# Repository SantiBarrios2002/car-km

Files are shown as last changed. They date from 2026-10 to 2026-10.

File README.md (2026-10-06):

# car-km — household car kilometre tracker

Logs every ride of the family car automatically and works out who drove how many kilometres each month.

A small device in the car reads distance from the OBD-II port over Bluetooth and records each ride. Tapping an NFC fob says who is driving. Rides are uploaded over WiFi to a Raspberry Pi at home, and the family uses a phone web app to see monthly totals, assign untapped rides ("that was me") and export CSV.

```
 car                                              home
┌──────────────────────────────────────┐        ┌───────────────────────────────┐
│ Vgate iCar Pro ─BLE─► ESP32-S3 module │  WiFi  │ Raspberry Pi                  │
│ (OBD-II speed)        + carrier PCB   │ ─────► │ FastAPI + SQLite (app/)       │
│ PN532 NFC ─I²C─►      (supercap hold- │  HTTP  │ web app at /, device API      │
│ (who drives)           up, 5 V input) │        │ at /api/  ◄── family phones   │
└──────────────────────────────────────┘        └───────────────────────────────┘
```

## Status

| Part | Where | State |
| --- | --- | --- |
| Pi service + web app | `app/` | **In use** on the family Pi. |
| Carrier PCB | `hardware/carrier/` | Schematic done (ERC clean); first-pass board placed, autorouted and passing DRC. **Not reviewed, not ordered.** |
| Car device firmware | `firmware/` | Not started. Conventions are already fixed in `CLAUDE.md`. |

### Next step: pre-order checks for the carrier PCB

None of these have been done yet. They come before anything is sent to a fab; details and commands are in [`hardware/README.md`](hardware/README.md#next-step-pre-order-checks).

1. **Review the board in KiCad**: placement, power trace widths, the autorouted tracks.
2. **Check the 3D fit** against Waveshare's STEP model (stack height, standoffs, cable paths).
3. **Re-run ERC and DRC** after any changes.
4. **Export the Gerber and drill files** and inspect them in a Gerber viewer.

## Repository layout

```
app/                  Pi service: FastAPI + SQLite, web app and device API
  main.py             all routes (web app + device API), sections marked with # ----
  db.py               schema and SQLite helpers
  static/index.html   the whole web app: one file, vanilla JS, Spanish/English
install.sh            Pi install: venv, systemd unit, nightly backup cron (safe to re-run)
car-km.service        systemd unit template used by install.sh
hardware/             car device hardware: Waveshare module + custom carrier PCB
  README.md           hardware design document: start here for the electronics
  carrier/            KiCad 10 project (schematic + PCB)
  bom-rev2.csv        bill of materials
  vendor/             Waveshare schematic and mechanical drawing (PDF)
CLAUDE.md             working notes for Claude Code and contributors: conventions, hard rules, hardware facts
```

`data/` (database, device token, firmware images, backups) is created at runtime and is not committed.

## Pi service

### Install on the Pi

```bash
git clone <this repo> ~/car-km
cd ~/car-km && chmod +x install.sh && ./install.sh
```

The script creates a venv, installs a systemd unit (`car-km.service`, port 8080) and a nightly SQLite backup cron, then prints the Tailscale URL to share with the family. Logs: `journalctl -u car-km -f`.

### Using it

- Open `http://<pi-tailscale-name>:8080` on a phone (see *Links*). On iOS, Share → *Add to Home Screen* makes it feel like an app.
- The first visit asks *¿Quién eres?*; the answer is remembered on that phone.
- **Ajustes**: add the people. Optionally log the real odometer reading once; after that a ride can be logged by typing the new odometer reading instead of km.
- **Apuntar**: km (or odometer) → Guardar. Rides can be back-dated.
- **Resumen**: monthly totals per person, with unassigned rides highlighted and a *Fui yo* button; the CSV button exports the month.
- Language (es/en) and €/km are set in Ajustes.

### Links (family setup)

| Where | URL |
| --- | --- |
| Anywhere, phone with Tailscale | http://iot-hub.tail8fe499.ts.net:8080 |
| Same, by Tailscale IP (if the name doesn't resolve) | http://100.102.81.29:8080 |
| Home WiFi, no Tailscale needed | http://192.168.1.140:8080 |
| API docs | http://iot-hub.tail8fe499.ts.net:8080/api/docs |

### Giving family members access (Tailscale)

At home the LAN link works for anyone on the WiFi. From outside, each person needs Tailscale. Prefer **sharing the Pi** over inviting people into the tailnet: someone you share with can reach only `iot-hub`, not your other devices.

1. In https://login.tailscale.com/admin/machines, open the **⋯** menu on `iot-hub` → **Share…** and copy the invite link.
2. Send it to the person. They install Tailscale (iOS/Android), sign in with their own Google/Apple/Microsoft account and open the link. They get their own free tailnet with `iot-hub` in it.
3. On their phone: Tailscale on → open the link above → Share / ⋮ → *Add to Home Screen*.
4. To revoke: admin console → **Machines** → `iot-hub` → **Share…** (or the **Sharing** tab) and remove them.

Alternatively, **Users → Invite users** makes them full tailnet members. That's simpler when they have many devices, but by default they can then reach every machine, so restrict them in **Access controls**.

### Device API (used by the car device)

| Method | Path | Auth | Purpose |
| --- | --- | --- | --- |
| POST | `/api/rides/batch` | bearer | JSON array of rides; idempotent on `(device_id, start_ts)` |
| GET | `/api/fobs` | none (also used by the web app) | fob → user map; send `If-None-Match` with the last ETag to get a 304 |
| GET | `/api/time` | bearer | server unix time, for setting the RTC |
| GET | `/api/firmware` | bearer | latest `firmware.bin`; send `X-Version` to get a 304 when current |

Bearer = `Authorization: Bearer <token>`. The token is in `data/device_token`, created on first start and shown in Ajustes. OTA images go in `data/firmware/` (`firmware.bin` + `version.txt`).

Ride object:

```json
{"device_id":"meriva-1","start_ts":1759742400,"end_ts":1759744230,"km":23.4,
 "fob_uid":"04A1B2C3D4E580","source":"obd","fw":"0.3.1","end_reason":"brownout"}
```

Interactive docs at `/api/docs`.

### Development

```bash
python3 -m venv .venv && .venv/bin/pip install -r requirements.txt
.venv/bin/uvicorn app.main:app --reload --port 8081
```

Port 8081 lets the dev server run alongside the live service on 8080. Run from the repo root: the default paths under `data/` are relative to the working directory.

### Security model

There are no logins: the app is reachable only on the home LAN and over Tailscale, and a household km log doesn't need more. The device API uses a bearer token. Don't expose port 8080 to the internet; if wider access is ever needed, put it behind Tailscale Serve or a reverse proxy with authentication.

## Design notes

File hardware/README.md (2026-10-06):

# car-km hardware — Rev 2: Waveshare ESP32-S3-Touch-LCD-2.8 + carrier PCB

The car device is an off-the-shelf **Waveshare ESP32-S3-Touch-LCD-2.8** (ESP32-S3, 2.8" touch display, RTC, Li-ion charger) mounted on a small custom **carrier PCB**. The carrier takes 5 V from the car's USB port, holds the module up for a few seconds after the ignition cuts power (so the ride can be saved), tells the firmware when that happens, and breaks out the PN532 NFC reader and a debug UART. Distance comes from a **Vgate iCar Pro** BLE OBD-II dongle, which needs no wiring.

## Status

| Item | State |
| --- | --- |
| Module facts | Verified against Waveshare's schematic and 2D drawing (`vendor/`), 2026-10-06. |
| Carrier schematic | `carrier/carrier.kicad_sch`, KiCad 10, ERC clean (0 violations). |
| Carrier PCB | `carrier/carrier.kicad_pcb`, first pass: placed, autorouted, DRC clean. **Not reviewed by a person, not ordered.** |
| Parts | Nothing bought yet except the OBD dongle (`bom-rev2.csv`). |

## Next step: pre-order checks

None of these have been done yet. Work through them in order before sending anything to a fab. All commands run from the repo root.

**1. Review the board in KiCad.** Open `hardware/carrier/carrier.kicad_pro`, then the PCB editor. Look at:
- **Routing:** the signals were autorouted (Freerouting) and nobody has looked at them yet. Tidy anything odd, especially the long USB_5V run to the fallback R3/D2. Those two parts aren't fitted by default, so that track could be shortened or moved.
- **Power trace widths:** 0.6 mm, which is the most J3's 1.0 mm-pitch pads and J1's VBUS pins allow. Widen the open runs (J1 → F1 → D1/JP1 → J3, J5 → JP2 → caps) where there is room.
- **Connector positions** against the real stack (see step 2): J1 on the bottom edge, J3 on the left edge, J5 on the right edge, J2 on the top edge.
- **Silkscreen:** pin-1 marks, cap polarity, the JP1/JP2 notes.
- After any edit, refill zones (`B`) before checking.

**2. Check the 3D fit.**
- Install the 3D models (`sudo apt install kicad-packages3d`, or use a KiCad install that has them).
- Download `ESP32-S3-Touch-LCD-2.8_3D.zip` from the [Waveshare wiki](https://www.waveshare.com/wiki/ESP32-S3-Touch-LCD-2.8) into `vendor/`. Don't commit it; it's 20 MB.
- Export the carrier: `kicad-cli pcb export step --subst-models -o hardware/carrier/carrier.step hardware/carrier/carrier.kicad_pcb`.
- Combine the two in FreeCAD (or the KiCad 3D viewer): the module sits on top, parts side facing the carrier, on 8 mm standoffs. Check:
  - **The gap between the boards.** The module's back parts are 6 mm tall, so about 2 mm is left. The carrier's inner face has no parts, but the through-hole leads of J2, J4, C1 and C4 stick out of it: trim them flush or check they clear.
  - **Total depth:** module 10 mm + standoffs 8 mm + carrier 1.6 mm + supercaps 20 mm standing (or ~9 mm lying flat).
  - **Cable paths:**
    - SH-12 cable from J3 round the left edge to module J8, which is in the lower-left quadrant of the module's back, about 12 mm from its left edge;
    - 2-pin cable from J5 to module J1 (BAT);
    - PN532 cable from J2.
  - **USB-C clearance:** a plug in the carrier's J1 near the module's own USB-C, which sits bottom centre.

**3. Re-run ERC and DRC** after any change:

```bash
kicad-cli sch erc --severity-all -o /tmp/erc.rpt hardware/carrier/carrier.kicad_sch
kicad-cli pcb drc --schematic-parity --severity-all -o /tmp/drc.rpt hardware/carrier/carrier.kicad_pcb
```

Expected: ERC 0 violations; DRC 0 errors, 0 unconnected, 0 parity issues. Two warnings are accepted: J1's library silkscreen runs off the board edge where the receptacle overhangs it.

**4. Export the fab files and inspect them.**

```bash
mkdir -p hardware/carrier/fab
kicad-cli pcb export gerbers --check-zones -l F.Cu,B.Cu,F.Paste,B.Paste,F.SilkS,B.SilkS,F.Mask,B.Mask,Edge.Cuts \
  -o hardware/carrier/fab/ hardware/carrier/carrier.kicad_pcb
kicad-cli pcb export drill --excellon-separate-th --generate-map -o hardware/carrier/fab/ hardware/carrier/carrier.kicad_pcb
```

Open the result in `gerbview` (ships with KiCad) or the fab's online viewer before uploading. The board is 2 layers, 1.6 mm, 69.0 × 49.9 mm, with a 0.2 mm minimum clearance and 0.15 mm minimum track (standard JLCPCB/PCBWay rules). `fab/` is not committed.

**After the boards arrive** (before the first car test):
- Change the module's R7 to ≥ 200 kΩ (see *Charge current*).
- Do the bench checks under *Still to verify*.

## The Waveshare module (from its schematic)

| Item | Fact | Consequence |
| --- | --- | --- |
| J8 "12-pin header" | **JST SH 1.0 mm, 12 pins** (`SH1.0-12P`) | The carrier connects with a 12-way SH cable; its J3 is an SH-12 socket. |
| J8 pinout | 1 GND · 2 **USB_5V** · 3 D− (IO19) · 4 D+ (IO20) · 5 GND · 6 3V3 · 7 SCL (IO10) · 8 SDA (IO11) · 9 UART_TXD (IO43) · 10 UART_RXD (IO44) · 11 **GPIO18** · 12 **GPIO15** | 5 V in, I²C, two spare GPIOs and UART on one cable. |
| USB → system | USB_5V → **D3 B5819WS** Schottky → VCC → **ME6217C33** LDO → 3V3 | USB has priority; VCC ≈ USB_5V − 0.3 V. D3 stops the battery rail back-feeding USB_5V. |
| Battery → system | BAT → **Q1 AO3401** (gate: R2 100 k to BAT, pulled low by **T2** when `BAT_Control` = IO7 is high, or by Key1) → **Q2 AO3401** (gate = USB_5V, R29 100 k to GND) → VCC | The battery path is on only when USB is absent **and** the firmware has driven IO7 high. Q2's body diode also conducts once VCC drops ~0.6 V below BAT. |
| Charger | **ETA6098** switching Li-ion charger, input = USB_5V, **RISET R7 = 82 kΩ → 2 A**, CV 4.2 V, 130 mA termination, restarts at −160 mV, input 4.5–5.5 V | Charges whatever is on the battery connector to 4.2 V. |
| Battery connector | J1, labelled **"PH1.25 2P"**: the 1.25 mm MX1.25 / Molex PicoBlade-compatible part (not JST PH 2.0 or GH). Pin 1 = BAT. | The supercap bank plugs in here, via the carrier's J5. |
| Pull-ups | R30 10 k to 3V3 on IO15 (SD_D2), R35 10 k on IO18 (SD_D1) | IO15 already has a pull-up, so the power-loss sense must drive it actively low. |
| BAT_ADC | IO8 reads BAT through 200 k / 100 k | Vbat = 3 × Vadc. |
| Backlight | NPN T3 on **IO5** | Turned off first when power is lost. |
| Antenna | Ceramic chip antenna (CA-C03) + U.FL, **top-left corner** in back view (ESP32 module upper-left, USB-C bottom centre) | Copper keep-out on the carrier under that corner. |
| Mechanical | PCB 69.00 × 49.90 mm, glass 73.06 × 50.54 mm, 10.0 mm total, **6.0 mm of parts on the back**. 4 holes on a **60.00 × 41.00 mm** grid, 4.50 mm in from the edges, Ø ≈ 2.7 mm (M2.5) | The carrier copies the outline and holes; standoffs ≥ 8 mm. |

## Carrier design

Schematic: `carrier/carrier.kicad_sch` (the source of truth for every net).

```
car USB ─ J1 USB-C ─ F1 PTC 1.1 A ─┬─ TVS1 SMAJ5.0A ─ GND
            VIN_CAR      VIN_FUSED ├─ R8 4k7 bleeder ─ GND
                                   ├─ R1 100k ─┬─ R2 11k3 ─ GND
                                   │           └─ U2 TPS3808G01 SENSE      ~RESET → J3.12 (IO15) = PWR_SENSE
                                   │              (VDD = module 3V3 via J3.6, C3 100n)
                                   └─ D1 SS34 ∥ JP1 (bridged) ─┬─ C2 10µF   USB_5V → J3.2
                                                               └─ TP1

module J1 (BAT) ─ cable ─ J5 PicoBlade ─ JP2 (bridged) ─ C1 5F/2.7V ─┬─ C4 5F/2.7V ─ GND
                                                          R4 10k ∥ C1  R5 10k ∥ C4
```

The carrier only protects (F1, TVS1), senses (U2), balances (R4/R5) and connects. Charging and switching to the caps happen on the module.

- **Hold-up.** The module's ETA6098 charges the 2 × 5 F bank (2.5 F, 5.4 V rated) to 4.2 V. When the car cuts power, USB_5V collapses (R8 bleeds it down; the module's D3 stops the board holding it up), Q2 turns on and the board runs from the caps. **Hold-up ≈ 5–7 s** with the backlight off: 2.5 F × (4.2 − 3.6 V) ÷ 0.2 A ≈ 7 s from a full bank, less because the charger only tops up after a 160 mV drop (~4.04 V). Saving the ride takes well under a second.
- **Power-loss sense (U2).** A TPS3808G01 supervisor watches VIN_FUSED through R1/R2 and drives IO15 low with its open-drain `~RESET`; the module's R30 is the pull-up.
  - Trip point: 0.405 V × (1 + 100 k / 11.3 k) = **3.99 V falling**. `~RESET` releases 20 ms after VIN_FUSED recovers (CT open).
  - U2 runs from the module's 3V3, which the caps hold up, so IO15 stays low for the whole hold-up. A supervisor powered from the car side would let IO15 float back high once the car rail fell below ~1 V.
  - A plain resistor divider can't do this job: R30 keeps IO15 high whether the car is on or off.
- **JP1 is bridged by default** (D1 bypassed). D1's drop plus the PTC and cable would leave ~4.4 V at J8, below the ETA6098's 4.5 V minimum input. D1 only matters in the fallback configuration.
- **Charge current.** Everything the module draws, up to 2 A of charge current included, comes in through J8 pin 2: one SH contact rated about 1 A, behind F1 (1.1 A hold). **Change the module's R7 (0402, back side) from 82 k to ≥ 200 k (≈ 0.8 A)** before the first car test. Recharging an empty bank then takes ~15 s instead of ~5 s.
- **Firmware duties:** drive IO7 (`BAT_Control`) high at boot and never low, otherwise the caps are never connected. Leave the microSD slot empty or use 1-bit SD mode, because IO15 is also SD_D2.

### Fallback configuration

This is for the case where the bench test shows the module's charger misbehaving with a capacitor load. Footprints for the Rev 1 circuit are on the board, unpopulated (DNP):
- **R3** (22 Ω, 1 W) from USB_5V to VCAP;
- **D2** (SS34) from VCAP back to USB_5V.

To switch over:
1. Cut JP1, so that D1 blocks back-feed into the car port.
2. Cut JP2.
3. Leave J5 unconnected.
4. Fit R3 and D2.

The caps then charge to ~4.7 V from the 5 V side and discharge into USB_5V through D2. Hold-up ≈ 2.5 F × (4.4 − 3.9 V) ÷ 0.2 A ≈ 6 s.

### Nets (summary)

| Net | Pins |
| --- | --- |
| VIN_CAR | J1 VBUS (A4, A9, B4, B9), F1.1 |
| VIN_FUSED | F1.2, TVS1 K, D1 A, JP1.1, R1.1, R8.1 |
| USB_5V | D1 K, JP1.2, C2.1, J3.2, TP1, R3.1 (DNP), D2 K (DNP) |
| SENSE_DIV | R1.2, R2.1, U2.5 SENSE |
| PWR_SENSE | U2.1 ~RESET, J3.12 |
| BAT | J5.1, JP2.1 |
| VCAP | JP2.2, C1 +, R4.1, TP2, R3.2 (DNP), D2 A (DNP) |
| VCAP_MID | C1 −, C4 +, R4.2, R5.1 |
| +3V3 | J3.6, J2.1, U2.6 VDD, U2.3 ~MR, C3.1 |
| SCL / SDA | J3.7 / J3.8 → J2.4 / J2.3 |
| NFC_IRQ | J3.11, J2.5 |
| UART_TX / UART_RX | J3.9 / J3.10 → J4.1 / J4.2 (module TXD / RXD) |
| USB_CC1 / USB_CC2 | J1 A5 / B5 → R6 / R7 5.1 k → GND |
| GND | J1 GND + shell, TVS1 A, R2, R5, R6, R7, R8, C2, C3, C4 −, U2.2, J2.2, J3.1, J3.5, J3/J5 mounting tabs, J4.3, J5.2, H2–H4 |

Not connected: J3.3 / J3.4 (USB D±), U2.4 CT (open = 20 ms delay), J1 D± and SBU. H1 is a bare hole.

### Connectors and cables

| Ref | Part | Mates with | Cable |
| --- | --- | --- | --- |
| J1 | USB-C 16-pin receptacle (HRO TYPE-C-31-M-12), power only | car USB cable | — |
| J3 | JST **SM12B-SRSS-TB** (SH 1.0 mm, 12-pin, side entry) | module J8 | 12-way SH, 80–120 mm, **same-side (type A)** so pin 1 maps to pin 1. Check with a meter before first power-up. |
| J5 | Molex **53261-0271** (PicoBlade 1.25 mm, 2-pin, SMD right angle) | module J1 (BAT) | 2-way 1.25 mm (Molex 51021-0200 housing both ends), 80 mm. Mind polarity: pin 1 = BAT on both. |
| J2 | JST **S5B-PH-K-S** (PH 2.0 mm, 5-pin, right angle) | PN532 module (DIP switch set to I²C) | 5-way PH to Dupont, 150–250 mm. Pins: 3V3, GND, SDA, SCL, IRQ. |
| J4 | 1 × 3 2.54 mm header | USB-UART dongle | J4.1 = module TX → dongle RX, J4.2 = module RX ← dongle TX, J4.3 = GND. |

## PCB layout (`carrier/carrier.kicad_pcb`)

- **Outline and stack:**
  - 69.00 × 49.90 mm, R2 corners, 2 layers, 1.6 mm.
  - The module sits on top, parts side down, on **8 mm M2.5 standoffs**; the carrier is behind it.
  - KiCad's top view is the carrier's outer face, which matches the module's back view: antenna top-left, USB-C bottom.
- **All parts are on the outer face** (F.Cu). The inner face stays empty because only ~2 mm is left under the module's 6 mm-tall back parts.
- **Holes:** Ø2.7 at (4.5, 4.5), (64.5, 4.5), (4.5, 45.5), (64.5, 45.5) in module coordinates (origin at the bottom-left, back view).
  - H1, top-left, sits inside the antenna keep-out and is a bare NPTH with no copper.
  - H2–H4 are plated and tied to GND.
- **Antenna keep-out:** 25 × 12 mm in the top-left corner, no copper on either layer, outlined on the silkscreen.
- **Placement:**
  - edges: J1 on the bottom edge, J3 on the left edge (opening outward, cable wraps round to J8), J5 on the right edge, J2 on the top edge right of the keep-out;
  - J4 bottom right;
  - supercaps C1/C4 top right;
  - car-input parts (F1, TVS1, D1/JP1) between J1 and J3;
  - sense circuit (U2, R1/R2, C3) next to J3.
- **Net classes** (stored in `carrier.kicad_pro`):

  | Class | Track | Via | Nets |
  | --- | --- | --- | --- |
  | Power | 0.6 mm | 0.8 / 0.4 mm | VIN_CAR, VIN_FUSED, USB_5V, BAT, VCAP, VCAP_MID |
  | GND | 0.4 mm | 0.6 / 0.3 mm | GND |
  | Default | 0.25 mm | 0.6 / 0.3 mm | all signals |

  Clearance is 0.2 mm everywhere. The 0.15 mm minimum track width allows the necked-down +3V3 entry into U2's SOT-23 pads.
- **GND:**
  - pours on both layers;
  - a fan-out via next to every SMD GND pad;
  - stitching vias across the board.
  F.Cu has track keep-outs under the J1, J3 and J5 bodies.
- **Routing:** Freerouting 2.5 via Specctra DSN/SES, with GND left to the pours. This is a first pass to tidy by hand (step 1 of the pre-order checks).

## Firmware hooks (ESP-IDF, Waveshare BSP)

| Signal | GPIO | Use |
| --- | --- | --- |
| BAT_Control | IO7 | **Output high at boot**, first line of `app_main`. Keeps Q1 on so the caps carry the board when power is lost. |
| BAT_ADC | IO8 | Vbat = 3 × Vadc. Show "backup OK" above 3.9 V; warn if the caps never reach 4.0 V. |
| PWR_SENSE | IO15 | Input; falling edge = car power lost → brownout handler. |
| LCD_BL | IO5 | Backlight; switched off first in the brownout handler. |
| NFC_IRQ | IO18 | Input; falling edge = PN532 has a tag. |
| I²C | IO10 SCL / IO11 SDA | Shared: PN532 0x24, PCF85063 RTC 0x51, QMI8658 IMU 0x6B. |
| Key_BAT | IO6 | Module button; unused. |

Brownout handler: backlight off → stop BLE polling → write `ride/live` → mark the ride closed → halt (`while (1) vTaskDelay`). In the halt loop, if IO15 reads high again (ignition back on while the caps still hold the board, so no power-on reset happens), call `esp_restart()`; U2's 20 ms release delay debounces this. On the next boot a leftover `ride/live` is closed and queued.

## Still to verify

Verified from Waveshare's files: J8 pitch and pinout, USB_5V on J8, power path, charger current, outline and hole grid, antenna position, IO15/IO18 pull-ups.

- [ ] Hole diameter: the STEP only shows a 4.3 mm ring. Measure it, or use Ø2.7 / M2.5 either way.
- [ ] Bench, supercaps:
  1. Caps on module J1, USB in; BAT should reach ~4.2 V (BAT_ADC or a meter).
  2. Set IO7 high, pull USB and time the hold-up with the backlight off. Target ≥ 5 s.
  3. Repeat on a 1 A-limited supply to imitate a weak car port.
- [ ] Bench: module current with backlight on/off and WiFi on/off (USB meter).
- [ ] SH cable is same-side (type A): check with a meter before first power-up.
- [ ] The car's USB port really goes dead at key-out.

## Bill of materials

`bom-rev2.csv`. Revision notes:
- **First Rev 2 draft:**
  - J3 is an SH-12 socket (not 2.54 mm);
  - J5 1.25 mm added;
  - D1 kept but bypassable;
  - R3/D2 kept as fallback footprints;
  - SH and 1.25 mm cables added.
- **2026-10-06 review (schematic rev A):**
  - U2 TPS3808G01 + C3 power-loss sense (R2 47 k → 11.3 k);
  - R8 4.7 k bleeder;
  - JP1 bridged by default;
  - J5 = Molex 53261-0271;
  - supercaps renamed C1a/C1b → C1/C4;
  - H1 changed to a bare NPTH;
  - holes, jumpers and test points dropped from the BOM.

## Later: Rev 2b

PN532 chip with a printed antenna on the carrier (NXP AN1445). This needs a NanoVNA for antenna tuning, and only makes sense once Rev 2 works.

## Sources

- Waveshare [ESP32-S3-Touch-LCD-2.8 wiki](https://www.waveshare.com/wiki/ESP32-S3-Touch-LCD-2.8): schematic and 2D drawing, copied into `vendor/` as `ESP32-S3-Touch-LCD-2.8_schematic.pdf` and `ESP32-S3-Touch-LCD-2.8_2D.pdf`; STEP model (not committed).
- ETA6096 datasheet via [LCSC](https://wmsc.lcsc.com/wmsc/upload/file/pdf/v2/lcsc/2307171444_etasolution-ETA6096D3K_C7465538.pdf). It is the same family as the module's ETA6098: RISET 82 k → 2 A, CV 4.2 V, 130 mA termination, 4.5–5.5 V input.
- TI TPS3808 datasheet: adjustable version (G01) with a 0.405 V threshold, open-drain `~RESET`, CT open = 20 ms delay.

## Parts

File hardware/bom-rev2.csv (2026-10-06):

group | ref | qty | part | package | source | approx_price_eur | notes
module | U1 | 1 | Waveshare ESP32-S3-Touch-LCD-2.8 (touch) | module 69.0x49.9mm PCB / 73.06x50.54mm glass | waveshare.com | 24 | brain, 2.8in IPS 240x320, PCF85063 RTC, PCM5101 amp, ETA6098 charger (2A), ESP32-S3R8 16MB/8MB
module | SPK1 | 1 | Speaker 8ohm 2W 2030 | 2030 | waveshare.com | 2 | plugs into module speaker header
module | BT1 | 1 | RTC backup cell (ML1220 or Waveshare-paired) | coin | waveshare.com | 2 | rechargeable; module charges it
reader | NFC1 | 1 | PN532 NFC module V3 (I2C/SPI/HSU DIP switch) | 40x43mm | amazon.es / aliexpress | 6 | set DIP to I2C: 1=ON 2=OFF; 3.3V logic
reader |  | 8 | MIFARE Classic 1K fob or NTAG213 sticker |  | amazon.es | 0.4 | 13.56 MHz ISO 14443A
cable |  | 1 | JST SH 1.0mm 12-pin ribbon cable same-side (type A) 100mm | SH 1.0 | aliexpress / lcsc | 1 | module J8 <-> carrier J3; verify pin1-to-pin1 with a meter
cable |  | 1 | 1.25mm 2-pin cable (MX1.25 / Molex PicoBlade 51021-0200 both ends) 80mm | 1.25mm | aliexpress / lcsc | 0.5 | module J1 BAT <-> carrier J5; mind polarity
cable |  | 1 | JST PH 2.0mm 5-pin to Dupont female 200mm | PH 2.0 | aliexpress / lcsc | 0.8 | carrier J2 <-> PN532 header
carrier | F1 | 1 | PTC resettable fuse 1.1A hold | 1812 | mouser/lcsc | 0.3
carrier | TVS1 | 1 | SMAJ5.0A unidirectional TVS | SMA | mouser/lcsc | 0.3 | clamps car adapter spikes
carrier | D1 | 1 | SS34 Schottky 3A 40V | SMA | mouser/lcsc | 0.15 | series isolation car -> USB_5V; JP1 can bypass
carrier | JP1 | 1 | solder jumper 2-pad (bridged) | SMD | - | 0 | bypass D1 (closed by default; cut for fallback config)
carrier | JP2 | 1 | solder jumper 2-pad | SMD | - | 0 | BAT -> VCAP (closed by default; open for fallback config)
carrier | R1 | 1 | 100 kohm 1% | 0805 | mouser/lcsc | 0.02 | U2 sense divider top (VIN_FUSED)
carrier | R2 | 1 | 11.3 kohm 1% | 0805 | mouser/lcsc | 0.02 | U2 sense divider bottom; trip 3.99 V falling
carrier | U2 | 1 | TI TPS3808G01DBVR adjustable supervisor (0.405 V) | SOT-23-6 | mouser/lcsc | 0.6 | power-loss sense; open-drain ~RESET to IO15 (PWR_SENSE); VDD from module 3V3
carrier | C3 | 1 | 100 nF 16V X7R | 0805 | mouser/lcsc | 0.02 | U2 VDD decoupling
carrier | R8 | 1 | 4.7 kohm | 0805 | mouser/lcsc | 0.02 | VIN_FUSED bleeder (~1 mA at 5 V)
carrier | R4 | 1 | 10 kohm | 0805 | mouser/lcsc | 0.02 | balance across C1
carrier | R5 | 1 | 10 kohm | 0805 | mouser/lcsc | 0.02 | balance across C4
carrier | R6 | 1 | 5.1 kohm | 0805 | mouser/lcsc | 0.02 | USB-C CC1 pulldown
carrier | R7 | 1 | 5.1 kohm | 0805 | mouser/lcsc | 0.02 | USB-C CC2 pulldown
carrier | C1 | 1 | Supercap 5F 2.7V low-ESR cylindrical | 8x20mm radial | mouser (Eaton HB / CDE DGH) or aliexpress | 1.5 | ESR <= 0.5 ohm; NOT coin-stack; mounts on outer face
carrier | C4 | 1 | Supercap 5F 2.7V low-ESR cylindrical | 8x20mm radial | mouser (Eaton HB / CDE DGH) or aliexpress | 1.5 | in series with C1
carrier | C2 | 1 | 10 uF 16V X5R | 0805 | mouser/lcsc | 0.05 | at J3 USB_5V
carrier | J1 | 1 | USB-C receptacle 16-pin (power-only wiring) | USB-C 16P | lcsc | 0.4 | car 5V in
carrier | J2 | 1 | JST S5B-PH-K-S (PH 2.0mm 5-pin right angle) | JST PH | lcsc | 0.2 | to PN532: 3V3 GND SDA SCL IRQ
carrier | J3 | 1 | JST SM12B-SRSS-TB (SH 1.0mm 12-pin side entry) | JST SH | lcsc | 0.5 | to module J8
carrier | J4 | 1 | 3-pin 2.54mm header | 2.54mm | lcsc | 0.1 | UART debug TX RX GND (optional)
carrier | J5 | 1 | Molex 53261-0271 (PicoBlade 1.25mm 2-pin SMD right angle) | 1.25mm | lcsc | 0.2 | supercap bank to module J1 BAT (vendor calls it PH1.25 = MX1.25)
carrier | TP1-TP2 | 2 | test point | SMD | lcsc | 0.05 | USB_5V, VCAP
carrier |  | 4 | M2.5 x 8mm standoff + M2.5 screws |  | amazon.es | 2 | module back components are 6 mm tall
carrier | PCB | 3 | Carrier PCB rev A 2-layer 1.6mm HASL 69.0x49.9mm |  | friend's fab or JLCPCB | 5
fallback | R3 | 1 | 22 ohm 1W | 2512 | mouser/lcsc | 0.2 | DNP by default; fallback config only
fallback | D2 | 1 | SS34 Schottky 3A 40V | SMA | mouser/lcsc | 0.15 | DNP by default; fallback config only
already_owned |  | 1 | Vgate iCar Pro BLE OBD-II |  | amazon.es | 30 | ordered separately
already_owned |  | 1 | Raspberry Pi running car-km service
already_owned |  | 1 | ESP32-S3 DevKitC-1 N16R8 |  |  |  | bench testing only

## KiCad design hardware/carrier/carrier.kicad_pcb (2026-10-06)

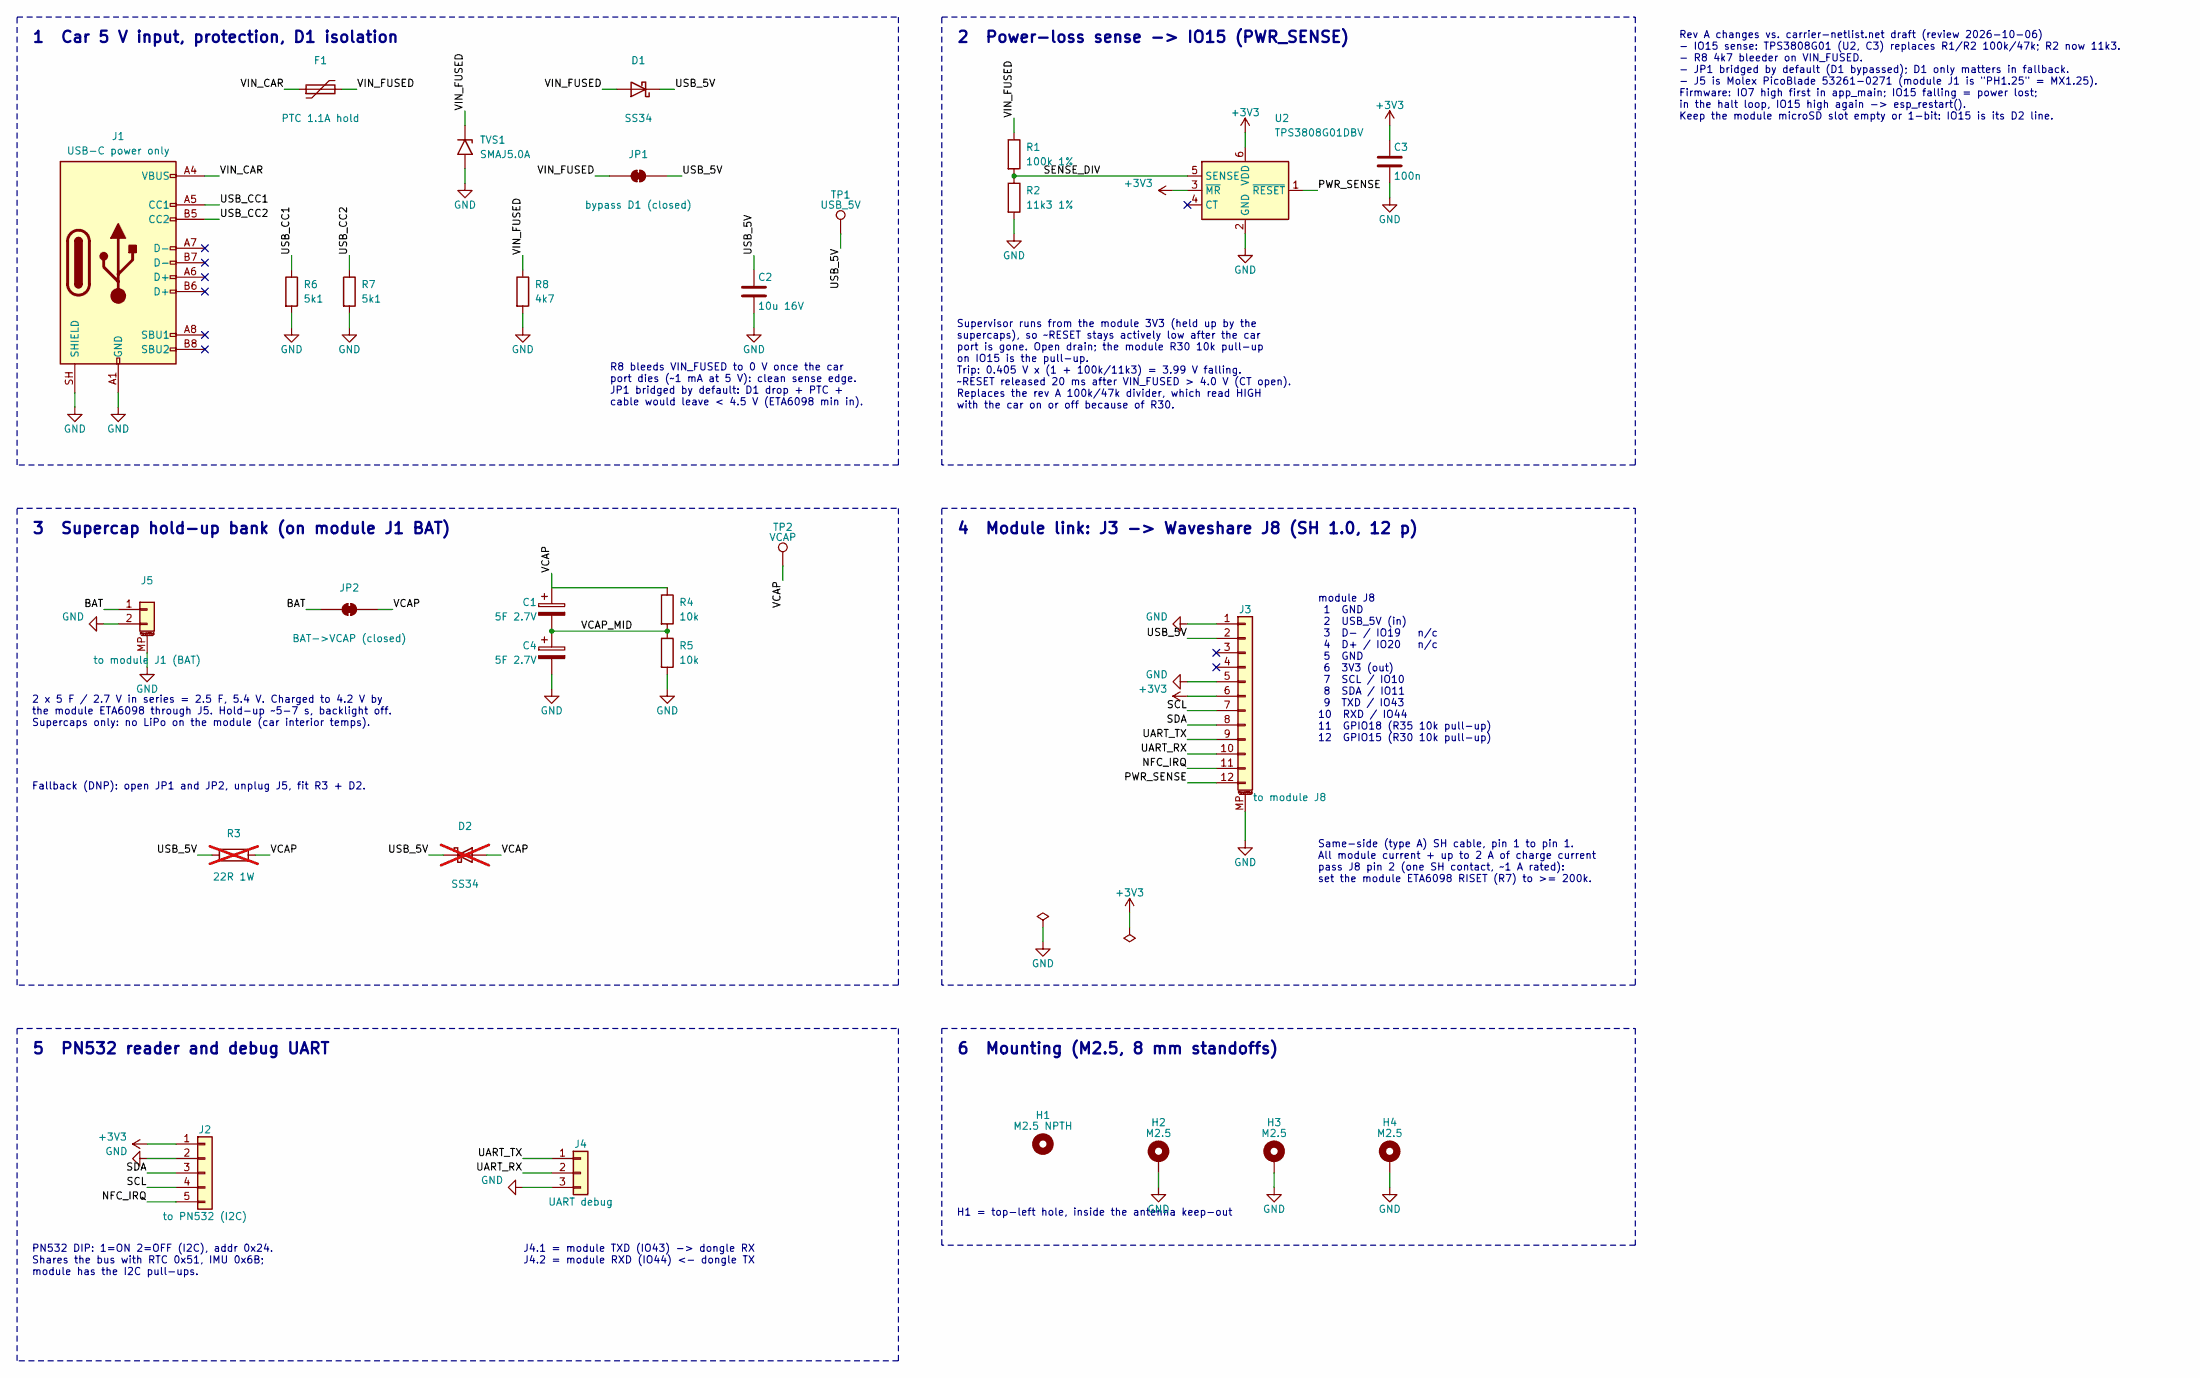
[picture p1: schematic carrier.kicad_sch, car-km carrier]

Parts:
C1, C4: 5F 2.7V; CP_Radial_D8.0mm_P3.50mm; MPN Eaton HB0820-2R5505-R class, ESR <= 0.5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
C2: 10u 16V; C_0805_2012Metric
C3: 100n; C_0805_2012Metric
D1: SS34; D_SMA
D2: SS34; D_SMA; not fitted
F1: PTC 1.1A hold; Fuse_1812_4532Metric
H1: M2.5 NPTH; MountingHole_2.7mm_M2.5
H2, H3, H4: M2.5; MountingHole_2.7mm_M2.5_Pad
J1: USB-C power only; USB_C_Receptacle_HRO_TYPE-C-31-M-12; MPN HRO TYPE-C-31-M-12
J2: to PN532 (I2C); JST_PH_S5B-PH-K_1x05_P2.00mm_Horizontal; MPN JST S5B-PH-K-S
J3: to module J8; JST_SH_SM12B-SRSS-TB_1x12-1MP_P1.00mm_Horizontal; MPN JST SM12B-SRSS-TB
J4: UART debug; PinHeader_1x03_P2.54mm_Vertical
J5: to module J1 (BAT); Molex_PicoBlade_53261-0271_1x02-1MP_P1.25mm_Horizontal; MPN Molex 53261-0271
JP1: bypass D1 (closed); SolderJumper-2_P1.3mm_Bridged_RoundedPad1.0x1.5mm
JP2: BAT->VCAP (closed); SolderJumper-2_P1.3mm_Bridged_RoundedPad1.0x1.5mm
R1: 100k 1%; R_0805_2012Metric
R2: 11k3 1%; R_0805_2012Metric
R3: 22R 1W; R_2512_6332Metric; not fitted
R4, R5: 10k; R_0805_2012Metric
R6, R7: 5k1; R_0805_2012Metric
R8: 4k7; R_0805_2012Metric
TP1: USB_5V; TestPoint_Pad_D1.5mm
TP2: VCAP; TestPoint_Pad_D1.5mm
TVS1: SMAJ5.0A; D_SMA
U2: TPS3808G01DBV; SOT-23-6; MPN TPS3808G01DBVR

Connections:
+3V3: C3.1, J2.1, J3.6, U2.3 (~MR), U2.6 (VDD)
/BAT: J5.1, JP2.1 (A)
/NFC_IRQ: J2.5, J3.11
/PWR_SENSE: J3.12, U2.1 (~RESET)
/SCL: J2.4, J3.7
/SDA: J2.3, J3.8
/SENSE_DIV: R1.2, R2.1, U2.5 (SENSE)
/UART_RX: J3.10, J4.2
/UART_TX: J3.9, J4.1
/USB_5V: C2.1, D1.1 (K), D2.1 (K), J3.2, JP1.2 (B), R3.1, TP1.1
/USB_CC1: J1.A5 (CC1), R6.1
/USB_CC2: J1.B5 (CC2), R7.1
/VCAP: C1.1, D2.2 (A), JP2.2 (B), R3.2, R4.1, TP2.1
/VCAP_MID: C1.2, C4.1, R4.2, R5.1
/VIN_CAR: F1.1, J1.A4 (VBUS), J1.A9 (VBUS), J1.B4 (VBUS), J1.B9 (VBUS)
/VIN_FUSED: D1.2 (A), F1.2, JP1.1 (A), R1.1, R8.1, TVS1.1 (A1)
GND: C2.2, C3.2, C4.2, H2.1, H3.1, H4.1, J1.A1 (GND), J1.A12 (GND), J1.B1 (GND), J1.B12 (GND), J1.SH (SHIELD), J2.2, J3.1, J3.5, J3.MP (MountPin), J4.3, J5.2, J5.MP (MountPin), R2.2, R5.2, R6.2, R7.2, R8.2, TVS1.2 (A2), U2.2 (GND)

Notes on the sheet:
Rev A changes vs. carrier-netlist.net draft (review 2026-10-06) - IO15 sense: TPS3808G01 (U2, C3) replaces R1/R2 100k/47k; R2 now 11k3. - R8 4k7 bleeder on VIN_FUSED. - JP1 bridged by default (D1 bypassed); D1 only matters in fallback. - J5 is Molex PicoBlade 53261-0271 (module J1 is "PH1.25" = MX1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
1 Car 5 V input, protection, D1 isolation
6 Mounting (M2.5, 8 mm standoffs)
2 Power-loss sense -> IO15 (PWR_SENSE)
R8 bleeds VIN_FUSED to 0 V once the car port dies (~1 mA at 5 V): clean sense edge. JP1 bridged by default: D1 drop + PTC + cable would leave < 4.5 V (ETA6098 min in).
2 x 5 F / 2.7 V in series = 2.5 F, 5.4 V. Charged to 4.2 V by the module ETA6098 through J5. Hold-up ~5-7 s, backlight off. Supercaps only: no LiPo on the module (car interior temps).
H1 = top-left hole, inside the antenna keep-out
4 Module link: J3 -> Waveshare J8 (SH 1.0, 12 p)
5 PN532 reader and debug UART
Supervisor runs from the module 3V3 (held up by the supercaps), so ~RESET stays actively low after the car port is gone. Open drain; the module R30 10k pull-up on IO15 is the pull-up. Trip: 0.405 V x (1 + 100k/11k3) = 3.99 V falling. ~RESET released 20 ms after VIN_FUSED > 4.0 V (CT open). Replaces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
PN532 DIP: 1=ON 2=OFF (I2C), addr 0x24. Shares the bus with RTC 0x51, IMU 0x6B; module has the I2C pull-ups.
3 Supercap hold-up bank (on module J1 BAT)
Same-side (type A) SH cable, pin 1 to pin 1. All module current + up to 2 A of charge current pass J8 pin 2 (one SH contact, ~1 A rated): set the module ETA6098 RISET (R7) to >= 200k.
J4.1 = module TXD (IO43) -> dongle RX J4.2 = module RXD (IO44) <- dongle TX
module J8 1 GND 2 USB_5V (in) 3 D- / IO19 n/c 4 D+ / IO20 n/c 5 GND 6 3V3 (out) 7 SCL / IO10 8 SDA / IO11 9 TXD / IO43 10 RXD / IO44 11 GPIO18 (R35 10k pull-up) 12 GPIO15 (R30 10k pull-up)
Fallback (DNP): open JP1 and JP2, unplug J5, fit R3 + D2.

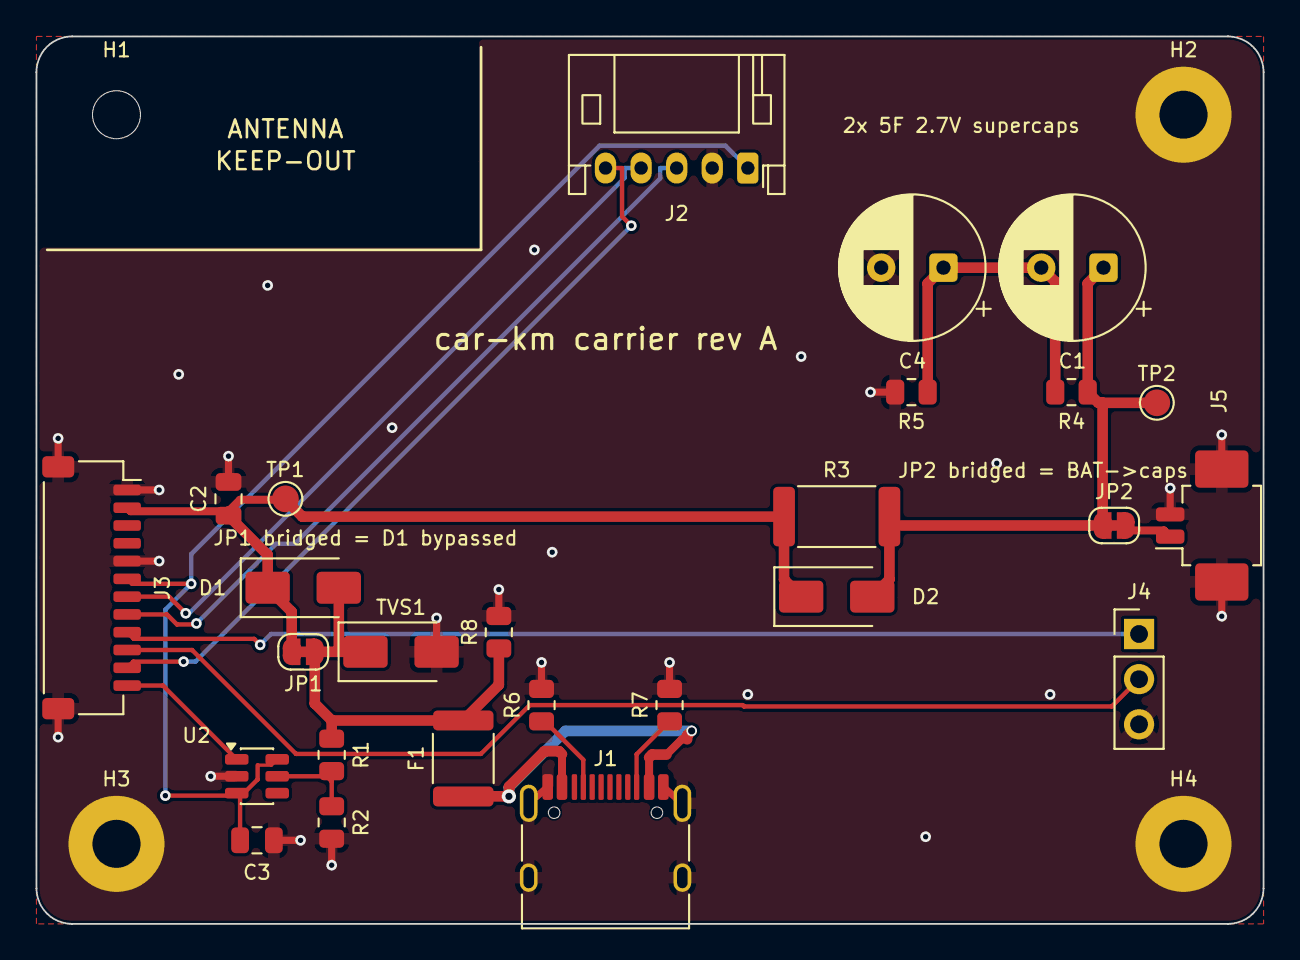
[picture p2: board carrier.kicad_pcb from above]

Board: 2 copper layers, 69.0 x 49.9 mm, 30 parts (0 on the bottom side), 17 nets.

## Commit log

2026-10-06 Add hardware rev 2 design: Waveshare module + carrier PCB
    README with part choices, power/hold-up design, carrier nets, layout rules,
    pre-order checks and build order; BOM; hand-written KiCad netlist for the
    carrier PCB.
    Claude-Session: https://claude.ai/code/session_01N4Uzk5HGCQB7admScT5Ery
    [bom-rev2.csv]
2026-10-06 hardware: rev 2 design checked against Waveshare schematic and drawing
    Carrier now feeds the supercaps through the module's own charger (J5 to
    module BAT), J3 becomes a JST SH-12 socket to match module J8, outline and
    holes copied from the 2D drawing, firmware GPIO hooks documented. R3/D2 kept
    as DNP fallback. Waveshare schematic and 2D drawing added under vendor/.
    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
    [bom-rev2.csv]
2026-10-06 hardware: fix netlist pad names so it imports cleanly into KiCad 10
    J1 shell pad is SH in the HRO TYPE-C-31-M-12 footprint, not S1; mounting
    holes use the _Pad variant so the GND nodes have a pad to land on.
    Verified by loading all footprints with pcbnew 10.0.6: 0 unresolved nodes.
    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
2026-10-06 hardware: carrier rev A KiCad schematic with review fixes
    Adds hardware/carrier/ (KiCad 10 project). The schematic replaces the
    hand-written carrier-netlist.net as the source of truth for nets; ERC is
    clean and every net was checked against the intended connections.
    Fixes from the 2026-10-06 review are built in:
    - IO15 sense: TPS3808G01 supervisor (U2, C3) on VIN_FUSED via R1/R2
    (100k/11k3, 3.99 V falling), open-drain into the module's R30 pull-up,
    powered from the held-up 3V3. The old 100k/47k divider read high with
    the car on or off.
    - R8 4k7 bleeder on VIN_FUSED.
    - JP1 bridged by default (D1 bypassed; it cost the ETA6098 its 4.5 V).
    - J5 is Molex PicoBlade 53261-0271 (module J1 "PH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
    [bom-rev2.csv, carrier.kicad_pcb, carrier.kicad_sch]
2026-10-06 hardware: KiCad project settings written on first open
    Claude-Session: https://claude.ai/code/session_01JQabpaYYgc1UrT8JpxmMza
2026-10-06 hardware: carrier rev A PCB first pass (placed, autorouted, DRC clean)
    - carrier.kicad_pcb: 69.0 x 49.9 mm outline with R2 corners, module hole
    grid, 25 x 12 mm antenna keep-out on both layers; all parts on the
    outer face; footprints linked to schematic symbols (parity clean).
    - Net classes in the project: Power 0.6 mm, GND 0.4 mm, signals 0.25 mm.
    - GND: pours both layers, fan-out via per SMD GND pad, stitching vias;
    F.Cu track keep-outs under the J1/J3/J5 bodies.
    - Signals autorouted with Freerouting 2.5 (DSN/SES), GND left to pours.
    - Schematic: H1 (under the antenna) is now a bare NPTH; holes, solder
    jumpers and test points are excluded from the BOM.
    DRC: 0 errors, 0 unconnected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
    [carrier.kicad_pcb, carrier.kicad_sch]
2026-10-06 hardware: KiCad's canonical net class order in project file
    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
2026-10-06 docs: clean README, hardware README and CLAUDE.md for new readers
    - README: project overview, status table, the carrier pre-order checks as
    the next step, repo layout; Pi service docs kept. /api/fobs documented
    as unauthenticated (matches the code); dev port 8081 as in CLAUDE.md.
    - hardware/README: status and "Next step: pre-order checks" first, with
    exact commands (review, 3D fit, ERC/DRC, Gerber/drill export); then
    module facts, carrier design, nets, connectors, PCB layout, firmware
    hooks, open checks, BOM history. Fixes stale vendor file names and the
    J3 position note.
    - CLAUDE.md: status and next step, KiCad workflow conventions, no-copper
    rule for the antenna keep-out.
    - .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
